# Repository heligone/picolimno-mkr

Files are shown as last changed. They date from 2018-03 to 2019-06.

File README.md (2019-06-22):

# picolimno-mkr

Télémètre à ultra-sons basé sur le carte Arduino MKRZERO et modem ADAFRUIT  FONA808mini - Mini Cellular GSM Breakout uFL Version (1946)

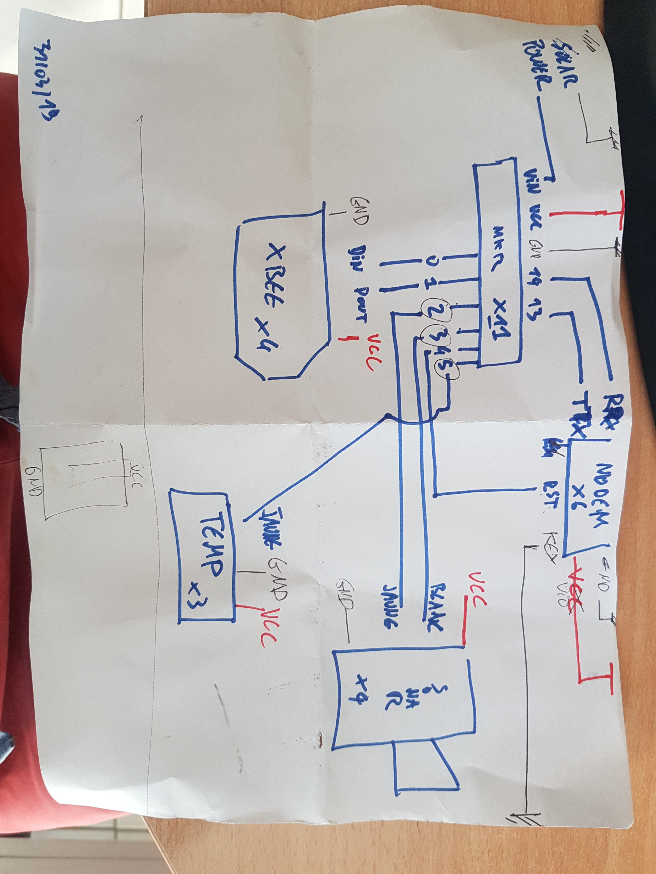
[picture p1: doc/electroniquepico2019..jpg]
plan

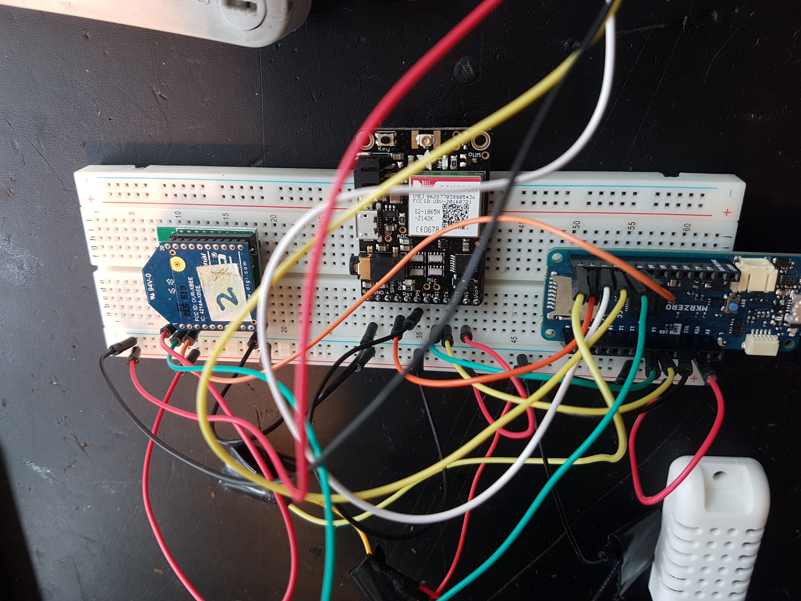
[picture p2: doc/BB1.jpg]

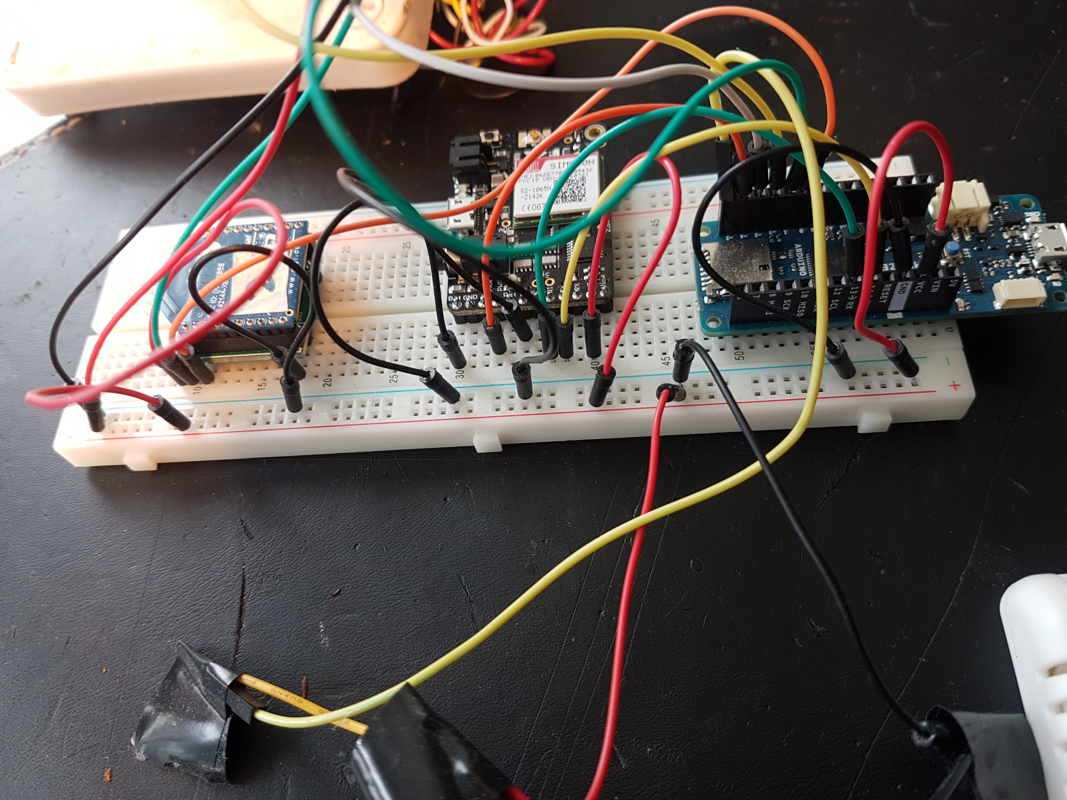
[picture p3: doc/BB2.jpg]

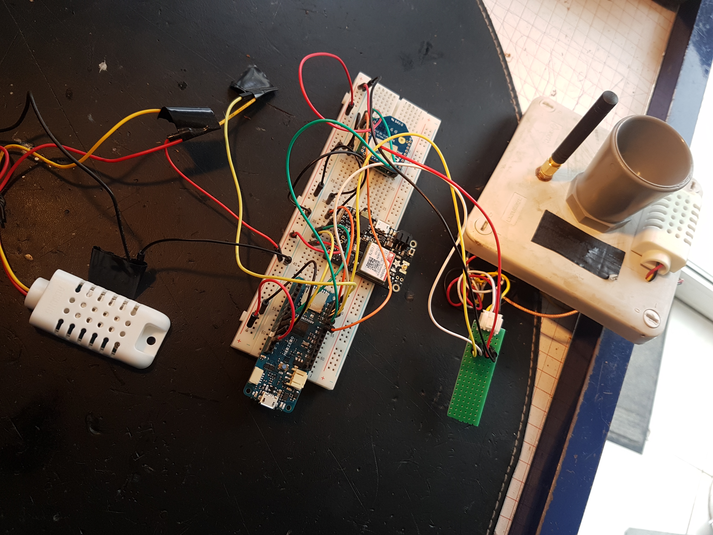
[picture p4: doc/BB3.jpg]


## electronique
astuce pour permettre reset du modem en cas de pb : bridger une diode une résistance pour permettre un hard reset depuis le MKR

see p 49 https://cdn-learn.adafruit.com/downloads/pdf/adafruit-fona-mini-gsm-gprs-cellular-phone-module.pdf

## Compilation
Après avoir cloner le répertoire, penser à ajouter le fichier
<code>secrets.h</code> qui devra contenir le code suivant :

```
/**
    Water-Level-MKRGSM1400 V1.0 project
    secrets.h
    Purpose: Define secrets for MKRGSM functions and others...
  
    @author Marc SIBERT
    @version 1.0 25/02/2018
    @warning *** This file shouldn't be uploaded in repo (Git) ***
*/
#pragma once

#define PIN_CODE ""

#define APN_NAME ""
#define APN_USERNAME ""
#define APN_PASSWORD ""
```

### Dépendances
* wiring_private
pour ajouter un port série suyr le mkrzero
* RTCZero :
  <code>Croquis > Inclure une biliothèque > RTCZero</code>
* ArduinoJson (https://github.com/bblanchon/ArduinoJson) :
  <code>Croquis > Inclure une biliothèque > Gérer les biliothèques</code> ; Ajouter "ArduinoJSON" dans le filtre et cliquer sur Installer.
* TinyGsmClient : bibliothèque de comande du modem
* ArduinoHttpClient : couche http
* StreamDebugger : pour debug avancé

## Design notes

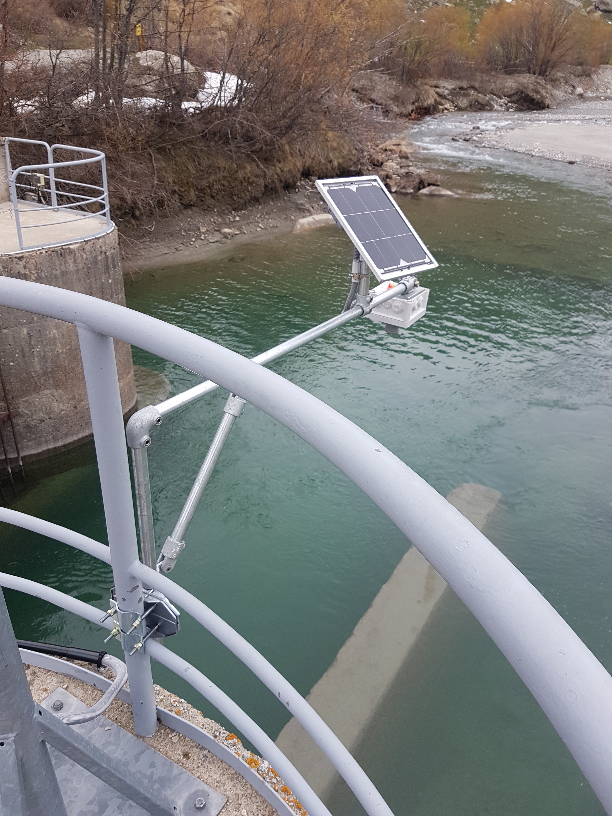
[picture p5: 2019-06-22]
doc/capteur.jpg

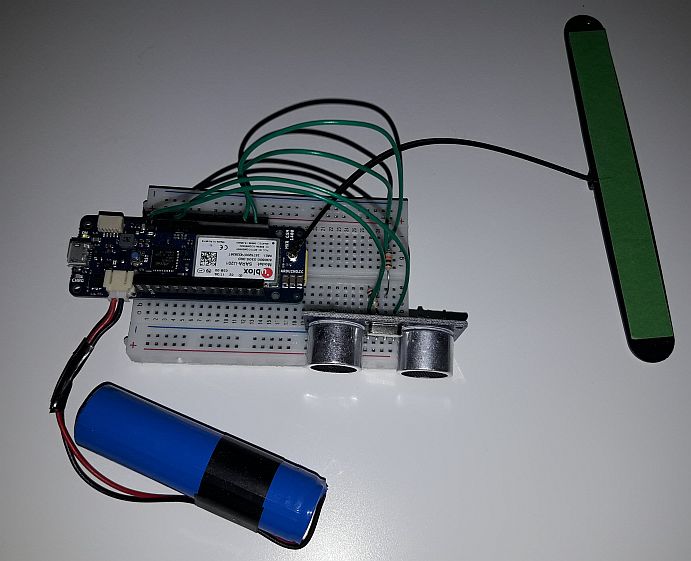
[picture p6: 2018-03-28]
doc/proto.jpg

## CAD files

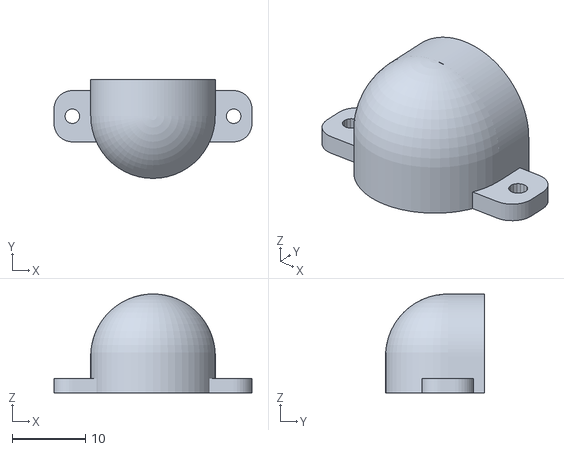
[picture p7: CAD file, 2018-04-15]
3D Boxing/picolimno-bouchon.stl
27.0 x 13.5 x 13.5

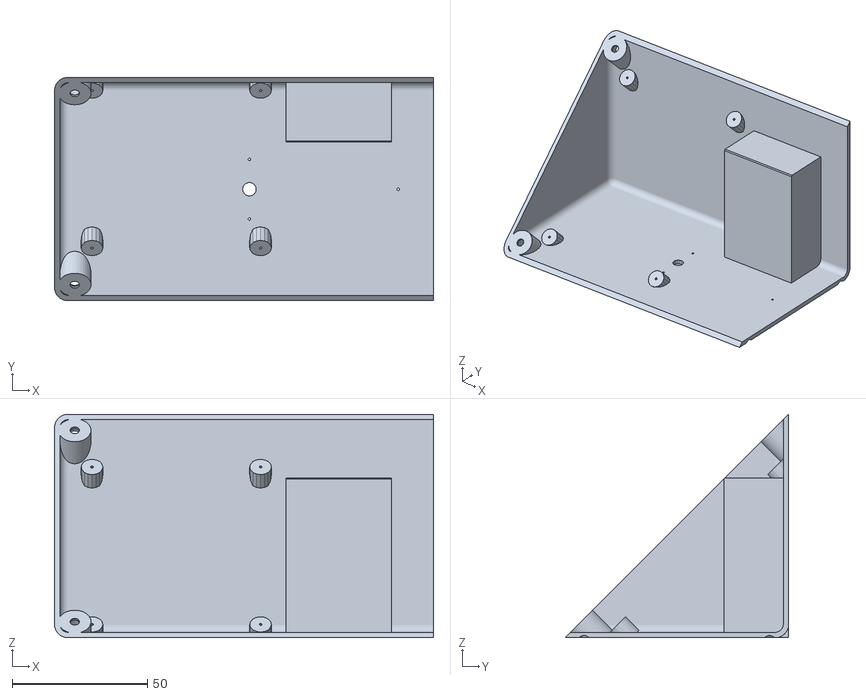
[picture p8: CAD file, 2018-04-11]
3D Boxing/picolimno-grand-côté.stl
140.0 x 82.5 x 82.5

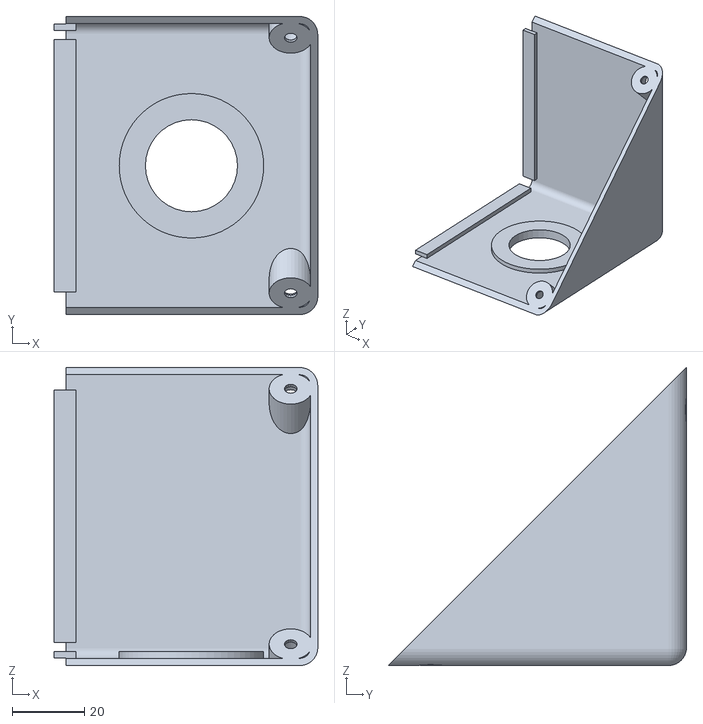
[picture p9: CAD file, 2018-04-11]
3D Boxing/picolimno-petit-côté.stl
73.0 x 82.5 x 82.5

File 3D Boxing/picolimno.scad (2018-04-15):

// Support
// translate([0, 30, -190]) cube([35, 20, 400], center=true);

module Panneau(tr = 5) {
// Plaque sous panneau solaire
    rotate([45,0,0]) difference() {
// façade
        hull() for (x=[-1,1]) for (y=[-1,1]) translate([x*(210/2-10),y*(115/2-10), tr]) cylinder(r=10, h=2, center=true);
// trous des vis            
        for (x=[-1,1]) for (y=[-1,1]) translate([x*195/2,y*100/2,5]) cylinder(r=2, h=3, center=true);
// trou du cable et attache
        translate([195/2-10,0,tr]) scale([1.5,1.0,1.0]) cylinder(r=10, h=3, center=true);
    }
};

module Boite(arrondi = 5, epaisseur = 2) {
    difference() {
        union() {
     // Tube du support
            translate([0,29.35,-11.8]) cube([39,24,59], center=true);

     // Boite
            difference() {
                hull() for (x=[arrondi-105,105-arrondi]) {
                    translate([x,41.35-arrondi,50-arrondi]) sphere(r=arrondi,$fn=36);
                    translate([x,arrondi-50,arrondi-41.35]) sphere(r=arrondi,$fn=36);
                    translate([x,41.35-arrondi,arrondi-41.35]) sphere(r=arrondi,$fn=36);
                }
                hull() for (x=[arrondi-105,105-arrondi]) {
                    translate([x,41.35-arrondi,50-arrondi]) sphere(r=arrondi-epaisseur,$fn=36);
                    translate([x,arrondi-50,arrondi-41.35]) sphere(r=arrondi-epaisseur,$fn=36);
                    translate([x,41.35-arrondi,arrondi-41.35]) sphere(r=arrondi-epaisseur,$fn=36);
                }
            }
            
    // Trous de fermeture (écrous)      
            intersection() {
                 rotate([45,0,0]) for (x=[-97.5,97.5]) for (y=[-50,50]) translate([x,y,-6.0]) cylinder(r=6,h=13,$fn=36,center=true);
                hull() for (x=[arrondi-105,105-arrondi]) for (i=[23,37]) {
                    translate([x,41.35-arrondi,i]) sphere(r=arrondi,$fn=36);
                    translate([x,-i,arrondi-41.35]) sphere(r=arrondi,$fn=36);
                }
            }
    // Épaulement du capteur US
        translate([70,0,-39]) cylinder(r=20,h=3,$fn=60,center=true);
        }

    // Trou de la barre
        translate([0,29.35,-15]) cube([35,20,61],center=true);
    // Trou de la vis de fixation
        translate([0,40.35,0]) rotate([90,0,0]) cylinder(r=2,h=3,center=true,$fn=16);
    // Tranchage de la façade
        translate([0,-7,7]) rotate([45,0,0]) cube([220,130,20],center=true);
    // Percement des trous de fixation de la façade
        rotate([45,0,0]) for (x=[-97.5,97.5]) for (y=[-50,50]) {
    // Trou du filetage
            translate([x,y,-1]) cylinder(r=1.75,h=3,$fn=16,center=true);
    // Trou de passage de l'écrou
            translate([x,y,-7]) cylinder(r=4,h=12,$fn=36,center=true);
        }
    // Trou du capteur US
        translate([70,0,-39.5]) cylinder(r=25/2+.25,h=5,$fn=36,center=true);
        
    // Goutte (rainure sur le dessous)
        hull() {
            translate([98,34.25,-43]) sphere(r=2.5,$fn=16);
            translate([98,-34.25,-43]) sphere(r=2.5,$fn=16);
        }
        hull() {
            translate([98,-34.25,-43]) sphere(r=2.5,$fn=16);
            translate([-98,-34.25,-43]) sphere(r=2.5,$fn=16);
        }
        hull() {
            translate([-98,-34.25,-43]) sphere(r=2.5,$fn=16);
            translate([-98,34.25,-43]) sphere(r=2.5,$fn=16);
        }
        hull() {
            translate([-98,34.25,-43]) sphere(r=2.5,$fn=16);
            translate([98,34.25,-43]) sphere(r=2.5,$fn=16);
        }

    // Épaulement & percements pour AM2302
        translate([0,0,-43]) cube([54,28,5],center=true);
        translate([22,0,-42]) cylinder(r=0.5,h=3,$fn=8);
        translate([-33,0,-42]) cylinder(r=2.5,h=3,$fn=16);
        translate([-33,11,-42]) cylinder(r=0.5,h=3,$fn=8);
        translate([-33,-11,-42]) cylinder(r=0.5,h=3,$fn=8);
    }

    // Tétons d'accrochage de la carte électronique
    difference() {
        translate([-60,7,-7]) rotate([45,0,0]) {
            for (y=[-82.25,82.25])
                for (x=[-62.25,62.25])
                    translate([x/2,y/2,-4]) difference () {
                        cylinder(r=4,h=7,$fn=16,center=true);
                        cylinder(r=0.5,h=8,$fn=16,center=true);
                    }
        }
        translate([0,0,-45]) cube([220,90,10],center=true);
        translate([0,45,0]) rotate([90,0,0]) cube([220,90,10],center=true);
    }
};

// Bouchon de AM2302
module Bouchon() {
    difference() {
        union() {
            hull() for(x=[-1,1]) for(y=[-1,1]) translate([11*x,y,-5]) cylinder(r=2.5,h=2,$fn=36);
            union() {
                hull() for(z=[0,-5]) {
                    translate([0,2.5,z]) rotate([90,0,0]) cylinder(r=8.5,h=5,center=true,$fn=104);
                }
                hull() for(z=[0,-5]) {
                    translate([0,0,z]) sphere(r=8.5,$fn=52);
                }
            }
        }
        hull() for(z=[0,-5]) {
            translate([0,9,z]) rotate([90,0,0]) cylinder(r=7.5,h=1,center=true,$fn=36);
            translate([0,0,z]) sphere(r=7.5,$fn=36);
        }
        translate([0,-1.75,-10]) cube([28,14.5, 10],center=true);
        for (x=[-1,1]) translate([x*11,0,-5 + 1]) cylinder(r=1,h=3,$fn=16,center=true);
    }
}



module GrandCote() {
    difference() {
        Boite();
        translate([85,0,0]) cube([100,100,100],center=true);
    };
};

module PetitCote() {
    intersection() {
        Boite();
        translate([85.25,0,0]) cube([100,100,100],center=true);
    };

    difference() {
        translate([35,0,-39]) cube([6,70,3], center=true);
        translate([32,0,-40]) cube([6.5,71,1.5], center=true);
    };

    difference() {
        translate([35,39,0]) cube([6,3,70], center=true);
        translate([32,40,0]) cube([6.5,1.5,71], center=true);
    };
};


// PetitCote();
// GrandCote();
Bouchon();

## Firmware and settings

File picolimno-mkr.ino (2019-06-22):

/*
 Licensed under the Apache License, Version 2.0 (the "License");
 you may not use this file except in compliance with the License.
 You may obtain a copy of the License at

    http://www.apache.org/licenses/LICENSE-2.0

 Unless required by applicable law or agreed to in writing, software
 distributed under the License is distributed on an "AS IS" BASIS,
 WITHOUT WARRANTIES OR CONDITIONS OF ANY KIND, either express or implied.
 See the License for the specific language governing permissions and
 limitations under the License.
*/

 /**
  * @file
    Picolimno MKR V1.0 project
    picolimno-mkr.ino
    Purpose: Main program calling App Class

    @author M. SIBERT
    @version 1.0 25/02/2018
*/
  Uart mySerial (&sercom3, 0, 1, SERCOM_RX_PAD_1, UART_TX_PAD_0); // Create the new UART instance assigning 

#define DEBUG_BUILD 1

#ifdef DEBUG_BUILD
#  define DEBUG(x) do { Serial.print(x);mySerial.print(x); } while(0)
#else
#  define DEBUG(x) do {} while (0)
#endif

#include "secrets.h"
/** 
    #define PIN_CODE
    
    #define APN_NAME
    #define APN_USERNAME
    #define APN_PASSWORD
*/

#include "App.h"

// for adding serial port ?
#include "wiring_private.h"

App& app = App::getInstance(F(APN_NAME), F(APN_USERNAME), F(APN_PASSWORD));

void setup() {



  pinPeripheral(0, PIO_SERCOM); //Assign RX function to pin 0
  pinPeripheral(1, PIO_SERCOM); //Assign TX function to pin 1
  // BT Serial
  mySerial.begin(57600);
  // USB Serial
  Serial.begin(57600);
  // GSM Serial
  Serial1.begin(57600);
//  while (!Serial) ;
  delay(5000);

  DEBUG(F(__FILE__)); DEBUG(F("\n"));
  DEBUG(F("Compiled on ")); DEBUG(F(__DATE__)); DEBUG(F("\n"));
  DEBUG(F(" at ")); DEBUG(F(__TIME__)); DEBUG(F("\n"));
  DEBUG(F(" for ")); DEBUG(F(USB_PRODUCT)); DEBUG(F("\n"));

  if (!app.setup()) {
    DEBUG(F("Error in App::Setup!")); DEBUG(F("\n"));
    exit(0);
  }
}

void loop() {
  if (!app.loop()) {
    DEBUG(F("Error in App::Loop!")); DEBUG(F("\n"));
    exit(0);
  }
}

  void SERCOM3_Handler()
{
  mySerial.IrqHandler();
}
 

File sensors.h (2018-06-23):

/*
 Licensed under the Apache License, Version 2.0 (the "License");
 you may not use this file except in compliance with the License.
 You may obtain a copy of the License at

    http://www.apache.org/licenses/LICENSE-2.0

 Unless required by applicable law or agreed to in writing, software
 distributed under the License is distributed on an "AS IS" BASIS,
 WITHOUT WARRANTIES OR CONDITIONS OF ANY KIND, either express or implied.
 See the License for the specific language governing permissions and
 limitations under the License.
*/

/**
 *  @file
 *  Picolimno MKR V1.0 project
 *  sensor.h
 *  Header of all sensors.
 *
 *  @author Marc Sibert
 *  @version 1.0 14/04/2018
 *  @Copyright 2018 Marc Sibert
 */

#pragma once

/**
 * Classe définissant les méthodes d'accès aux capteurs ainsi que de leur initilisation et celle du contrôleur.
 * La méthode begin() permet une intialisation tardive (lazy setup).
 * Le contructeur de fait qu'initialiser les variables d'instance.
 * @warning On ne DOIT pas instancier plusieurs fois cette classe ; c'est un syngleton.
 */
class Sensors {

private:
/// Ports
  const int mbTriggerPin, mbEchoPin, amDataPin;

protected:

  bool readAM2302(float& aTemp, float& aHygro) const {
    pinMode(amDataPin, OUTPUT);
    digitalWrite(amDataPin, LOW);   // down
    delayMicroseconds(1000);    // wait 1 ms
    pinMode(amDataPin, INPUT_PULLUP);
    
    const unsigned p = pulseIn(amDataPin, LOW, 150U);    
    if (p < 70 || p > 90) return false;   // should be about 80 ms or an error

    uint16_t hygro = 0;
    for (byte i = 16; i > 0; --i) {
      const unsigned p = pulseIn(amDataPin, HIGH, 150U);
      if (!p) return false;   // timeout
      hygro *= 2;
      if (p > 50) ++hygro;
    }

    uint16_t temp = 0;
    for (byte i = 16; i > 0; --i) {
      const unsigned p = pulseIn(amDataPin, HIGH, 150U);
      if (!p) return false;   // timeout
      temp *= 2;
      if (p > 50) ++temp;
    }

    uint8_t chk = 0;
    for (byte i = 8; i > 0; --i) {
      const unsigned p = pulseIn(amDataPin, HIGH, 150U);
      if (!p) return false;   // timeout
      chk *= 2;
      if (p > 50) ++chk;
    }

    if ( ((temp & 0xff00) / 256 + (temp & 0x00ff) + (hygro & 0xff00) / 256 + (hygro & 0x00ff) - chk) & 0x00ff ) return false;
  
    aHygro = hygro / 10.0f;
    aTemp = (temp & 0x8000 ? -1 : 1) * (temp & 0x7fff) / 10.0f;

    return true;
  }



public:
/**
 * Constructeur initialise les constantes matérielles.
 * Ne réalise aucune action.
 */
  Sensors(const int& mbTrigger, const int& mbEcho, const int& amData) :
    mbTriggerPin(mbTrigger),
    mbEchoPin(mbEcho),
    amDataPin(amData)
  {};

/**
 * Configure les ports et active les capteurs.
 * @return Le succès de l'initilisation, ou pas.
 */
  bool begin() {
    analogReadResolution(10);
  
    pinMode(mbEchoPin, INPUT);
    digitalWrite(mbTriggerPin, LOW);
    pinMode(mbTriggerPin, OUTPUT);

    pinMode(amDataPin, INPUT_PULLUP);

    return true;
  };

/**
 * Retourne la distance mesurée par le capteur Maxbotix MBxxxx.
 * "To calculate the distance, use a scale factor of 58uS per cm." 
 * ou pas !!! je comprends pas, mais la mesure est correcte.
 * 
 * @return La distance mesurée exprimée en mm ou 0 si la mesure est invalide (hors interval).
 */
  unsigned long sampleRange() const {
    digitalWrite(mbTriggerPin, HIGH);
    delayMicroseconds(100); 
    digitalWrite(mbTriggerPin, LOW);

    const unsigned long start = millis();
    const unsigned long pulse = pulseIn(mbEchoPin, HIGH, 170000UL); // attendre env. 148 ms (mesure et calcul)
    while (millis() - start < 170) ;  // attendre en tout 166ms avant la fin de toute la transmission
    return (pulse < 600) || (pulse > 9000) ? 0 : pulse; // Hors interval : retour 0 == mesure invalide
  }

/**
 * Lance un échantillonnage et indique à la fois la température et l'humidité mesurées.
 * @see https://cdn-shop.adafruit.com/datasheets/Digital+humidity+and+temperature+sensor+AM2302.pdf
 * @note Lance deux fois la mesure car la première et parfois suspecte.
 * 
 * @param aTemp Retourne la température mesurée en °C.
 * @param aHygro Retourne le taux d'humidité dans l'air en %H.
 * @return Le succès de la collecte des résultats, ou pas ; en cas d'échec, les paramètres précédents doivent être ignorés.
 */
  bool sampleAM2302(float& aTemp, float& aHygro) const {
    readAM2302(aTemp, aHygro);
    delay(500);
    return readAM2302(aTemp, aHygro);
  }


/**
 * Mesure la tension de la batterie LiPo.
 * La valeur est une moyenne sur 10 échantillons successifs.
 * 
 * @return La tension en volts.
 */
  float sampleBattery() const {
    unsigned long a = 0;
    for (int i = 0; i < 10; ++i) {
      a += analogRead(ADC_BATTERY);
    }
    return(a * (3.3f * 153) / (1024 * 120.0f) / 10.0f);
  }
};

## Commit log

2018-03-28 transmission ok et mesure avec MB7363
    Trouvé de bug de transmission (limite à 255 car : tronqué)
    Modif pour utilisation du capteur distance MB7363
    Buffer à 100 échantillons
    [App.h]
2018-04-02 Moyenne sur 10 mesures de batterie
2018-04-05 Essai de boite du picolimno
    [picolimno-bouchon.stl, picolimno-grand-côté.stl, picolimno-petit-côté.stl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]
2018-04-05 Rename picolimno.scad to 3D Boxing/picolimno.scad
    [picolimno.scad]
2018-04-05 Rename picolimno-bouchon.stl to 3D Boxing/picolimno-bouchon.stl
    [picolimno-bouchon.stl]
2018-04-05 Rename picolimno-grand-côté.stl to 3D Boxing/picolimno-grand-côté.stl
    [picolimno-grand-côté.stl]
2018-04-05 Rename picolimno-petit-côté.stl to 3D Boxing/picolimno-petit-côté.stl
    [picolimno-petit-côté.stl]
2018-04-11 Oups mesurerDistance avec des constantes
    Changé avec les enum ports
2018-04-14 Sortie du code des capteurs dans sensors.h
    Réorganisation du code
    Ajout des entêtes Licence Apache 2.0
2018-04-15 Ralonge du bouchon
    ajout de 5 mm de hauteur
    [picolimno-bouchon.stl, picolimno.scad]
2018-04-15 Gestion des paramètres
    @todo terminer l'analyse de la reponse du serveur api
2018-04-19 Passage des échanges en HTTPS
    Manque encore l'authentification
2018-04-19 Ajout des dépendances
2018-04-19 Amélioration de http::get
    Mais c'est pas encore ça
2018-04-21 Avec trace des mesures en temps réel
2018-04-24 Update App.h - Ajout de tests de validité de l'heure (#12)
    * Phase I vérification de la cohérence
    * Phase II utilisation de l'heure NTP
    Pour le moment l'IP du serveur est codée en dur
2018-04-26 Ajout des tests et de la reprise de GPRS
    A voir sur le pico de Sam
2018-05-03 Intégration de ArduinoHttpClient
2018-05-09 Utilisation de tinyGSM pour les requetes HTTP
2018-05-09 Déplacement de rtc.begin()
2018-05-11 Remove debug trace
2018-05-14 Remplacement du tri InsertionSortR par un quickSort
2018-05-16 Correction bug Internal Error PUT-3
    C'est un timeout de httpclient ; je fais donc 3 tentatives avant de déclarer un échec.
    En cas d'échec, dans loop(), on ne bloque plus la poursuite.
    [App.h]
2018-05-23 Suppression des échantillons hors interval
2018-05-23 Mesure "brut" transmise toutes les 15 min
2018-05-23 Divers correctifs sur les commits de la journée
    [App.h]
2018-05-26 Correction bug médiane #27
    Mais aussi modification de la logique : jusqu'à 2 * plus de mesures pour atteindre l'objectif du nombre d'échantillons valides
    [App.h]
2018-05-26 jusqu'à 5x le nombre mini de mesures brutes
2018-05-26 message d'alerte de mesure invalide
2018-05-27 détails
    qques modifs que je refais à cahque fois :
    - serial1 pour xbee
    - affichage des mesures matérielles en dubug dans la console
    + changement pour les seuils dans alert.h : j'enlève le coté "symétrique" pour etre sur que les alertes sont bien calculées sur le bon seuil
2018-05-27 affichage du train de mersures encadrées
2018-05-30 Constantes RANGE_SEQ MAX & MIN pour contrôler la séquence
2018-05-30 Retry Connect. GSM & GPRS sur les sendStatus & sendSample
2018-06-03 Ajout de la librairie ArduinoJson
2018-06-03 Une (bonne) piste pour la lecture des paramètres au démarrage
2018-06-09 Multi
    - correction du bug du nombre mini d'échantillons (parfois inf. à RANGE_SEQ_MIN)
    - prise en compte des paramètre Alert1 & Alert2, heure de début de mesures et heure de fin
    [App.h]
2018-06-09 Corrections mineurs (pas tant que ça)
    Passage au DynamicBuffer
    Veille hasardeuse corrigée
    [App.h]
2018-06-10 Déclenche ttes les min et transmet au 1/4 d'heure entiers
2018-06-10 Prise de l'heure dans la réponse HTTP des paramètres
2018-06-10 Correction du bug de Novembre
    [App.h]
2018-06-12 Correction du bug des alertes
    pfff la vieillesse ça fait des ravages
    [App.h]
2018-06-12 Suppression message Réglage de l'Heure
2018-06-19 Reboot à 00:00 et double mesure de temp
    Ajout du param. "reset":"hh:mm" ex : reset: "00:00" (attention en UTC)
    [App.h, sensors.h]
2018-06-20 Condition de sortie et tabulation de Loop
2018-06-20 Correction perte de temp.
    [App.h, sensors.h]
2018-06-20 Initialisation des alertes à partir d'une première mesure de distance
2018-06-23 init alertes
    - alert initialisée à true dans constructeur pour que si démarrage dans hysteresis, l'alerte se déclence au niveau d'eau montant
    - delay 500 pour double mesure temp
2018-08-06 Nouvelle version de test de la connexion avant la transmission
2018-08-18 Revert "Nouvelle version de test de la connexion avant la transmission"
    This reverts commit feddd9769fac242aac72d66f3ec46a2b52bb97d6.
    [App.h, communication.h]
2018-08-18 Fin de l'intégration de communication.h
    Debug profond de communication.h
2018-08-31 Reboot physique duy modem à chaque envoi
    insertion du code de reset physique du modem dans connectGSMGPRS()
    dans communicaions.h L90 :
    bool getParameters(const String &aIMEI devient bool getParameters(const String aIMEI
    Sinon l'IMEI n'est pas conservé pour les PUT et les GET
    Note : si l'IMAI initial n'est pas obtenu, aucune transimission n'est possible par la suite !
    [App.h, communication.h, picolimno-mkr.ino]
2018-09-02 suppression de client.stop() dans communication/h
    J'ai noté dans les log AT que cette commande renoyait une erreur.
    Note : il reste des erreurs dans les logs AT pour le PUR mais pas pour les GET
